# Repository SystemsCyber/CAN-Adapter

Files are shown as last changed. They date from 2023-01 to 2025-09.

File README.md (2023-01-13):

# CAN Adapter

The CANTool utilizes a Teensy 4.1 and a general expansion port as an add on if needed. There are three CAN channels available for use as well as 4 LED's to be programmed for desired use.

## Testing

There are a few test programs located in the tests folder allowing for the device's functions to be verified. The tests within the folder include tests for the SD card, all 3 CAN channels, LED blinking, and the D-SUB.

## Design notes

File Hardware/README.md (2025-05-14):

# Teeny 4 CAN Tool

This directory has PCB schematics, BOMs, and Altium PCB project files.

All components are through hole, so it is easy to build with just a soldering iron.

PDFs of the !(schematics)[Teensy%204%20CAN%20Tool%20Rev2%20Schematics.pdf] are available.

## Self-Assembly Instructions

If using a powered connection, pins 3 and 6 are shorted together on the ground pin. However, pin 6 can also be pin 9 of the dsub is inverted, which will short the power to ground. Therefore, please cut the trace between pin 3 and 6 on the bottom of Version 2 of the board on the DSUB connection.

### Materials

- Soldering iron
- Solder
- Teensy 4 CAN Tool PCB
- 30 AWG wire
- Wire cutters and strippers
- Good ventilation and lighting
- Bill of materials and all items listed
- PCB mount (recommended)
- Solder wick (recommended)

### Assembly

It is **highly** recommended assembling the board starting with the lowest profile components first (i.e. resistors and small capacitors) and the highest profile components near the end (i.e. headers, phoenix contacts, and jumpers). That way, it is much easier to align pins and solder the components properly or correct mistakes.

Solder items carefully, ensuring that pins are not bridged or lacking solder. Be wary of polarity for large capacitors and diodes. Properly dispose of component clippings.

The recommended order of population:

- Resistors (470 Ohm x4, 120 Ohm x3)
- Small Capacitors (0.1uF x3)
- IC (MCP2562 x3)
- LED's (GRN, YLW, RED, BLU)
- Headers (Female, 24 pin x2, 8 pin x2)
- Connectors (6 pin x1)
  - Cut into 3 sets of 2 pins each for the jumper connections
- Phoenix Contacts (x3)
- DSUB Connector
- Add terminating connections last (x3)

As for the Teensy 4.1 Board, solder (2x 24 pin Male Headers) then it can be directly placed onto the female headers on the CAN Tool PCB.

## Errata

The PCB board on revision 1 needs 30 AWG wire to be soldered from:

* CANH on Phoenix Connector to Pin 7 (CANH) on MCP2562 Designator U2
* Can RX/TX 3 to MCP2562 Designator U3
  * RX = Pin 30 On Teensy 4.1 -> Pin 4 (RX) on U3 MCP2562FD
  * TX = Pin 31 on Teensy 4.1 -> Pin 1 (TX) on U3 MCP2562FD

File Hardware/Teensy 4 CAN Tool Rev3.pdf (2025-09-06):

MikroBus Expansion | Vehicle Network Connection

# CAN Transceivers

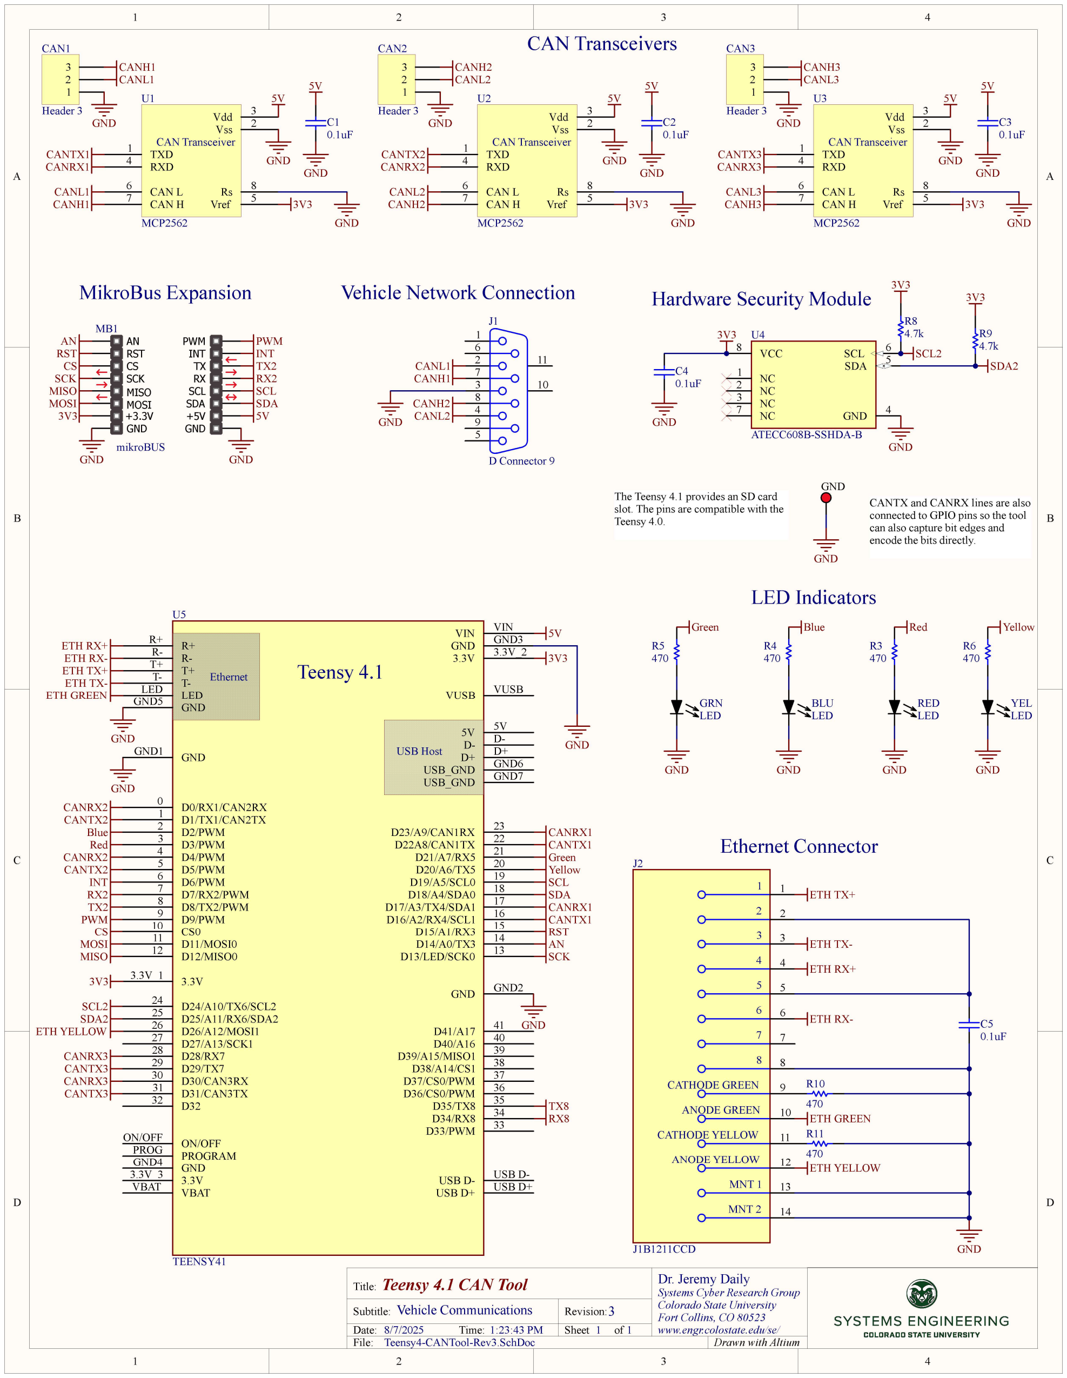
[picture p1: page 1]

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
Systems Cyber Research Group Colorado State University
Fort Collins, CO 80523

### 1 www.engr.colostate.edu/se/

## Teensy 4.1 CAN Tool

Vehicle Communications | 3
8/7/2025 | 1:23:43 PM
Teensy4-CANTool-Rev3.SchDoc

Title:

Subtitle:
Date:
File:

Revision:
Time: | Sheet | of
Drawn with Altium

### Dr. Jeremy Daily

3V3

GND
CANRX2
CANTX2

5V

CANRX1
CANTX1

TXD 1

Vss | 2
Vdd | 3

RXD 4

Vref 5

CAN L 6
CAN H 7

Rs 8

CAN Transceiver

U1

MCP2562

3V3

5V

GND

CANL1
CANH1
GND

1

2

3

CAN1

Header 3
GND

CANL1

CANRX1

CANTX1 | TXD 1
Vss | 2
Vdd | 3

RXD 4

Vref 5

CAN L 6
CAN H 7

Rs 8

CAN Transceiver

U2

MCP2562

3V3

5V

GND

CANL2
CANH2
GND

1

2

3

CAN2

Header 3
GND

CANL2

CANH2

CANRX2

CANTX2

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
Blue

GND | GND | GND GND
Green | Yellow Red

Green

Blue

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
D Connector 9

CANL1
CANH1

CANL2

CANH2
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
Yellow

CANRX3
CANTX3

TXD 1

Vss | 2
Vdd | 3

RXD 4

Vref 5

CAN L 6
CAN H 7

Rs 8

CAN Transceiver

U3

MCP2562

3V3

5V

GND

CANL3
CANH3
GND

1

2

3

CAN3

Header 3

CANL3

CANTX3
CANRX3

AN
RST
CS
SCK

MOSI

MISO

+3.3V
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
mikroBUS
GND | GND
3V3 | 5V

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
MOSI

MOSI

MISO

MISO

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
0.1uF

GND

5V

C2
0.1uF

GND

5V

C1
0.1uF

GND

5V

The Teensy 4.1 provides an SD card slot. The pins are compatible with the Teensy 4.0.

CANRX2
CANTX2

CANRX3
CANTX3

CANTX and CANRX lines are also connected to GPIO pins so the tool can also capture bit edges and encode the bits directly.

CANRX1
CANTX1

SCL2
SDA2

RX8

TX8

VCC 8

| SCL | 6
| SDA | 5
NC 1
NC 2
NC 3
NC 7 | GND | 4

U4

ATECC608B-SSHDA-B

C4
0.1uF

GND

GND

3V3

3V3
3V3

SCL2
SDA2

R8
4.7k | R9
| 4.7k

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
CATHODE GREEN

ANODE GREEN

CATHODE YELLOW

ANODE YELLOW

MNT 1

MNT 2

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
J1B1211CCD

# Ethernet Connector

VIN VIN

D5/PWM 5

PROGRAM PROG ON/OFF ON/OFF

D0/RX1/CAN2RX 0
D1/TX1/CAN2TX 1

D7/RX2/PWM 7
D8/TX2/PWM 8

D28/RX7 28
D29/TX7 29
D34/RX8 | 34 D35/TX8 | 35

D30/CAN3RX 30
D31/CAN3TX 31

D3/PWM 3
D4/PWM 4
D33/PWM | 33
D13/LED/SCK0 | 13 D14/A0/TX3 | 14 D15/A1/RX3 | 15 D16/A2/RX4/SCL1 | 16 D17/A3/TX4/SDA1 | 17 D18/A4/SDA0 | 18 D19/A5/SCL0 | 19 D20/A6/TX5 | 20 D21/A7/RX5 | 21 D22A8/CAN1TX | 22
5V | 5V

3.3V 3.3V_1

3.3V 3.3V_2

3.3V 3.3V_3

VUSB VUSB

VBAT VBAT

LED LED | T- T- | T+ T+ | R- R- | R+ R+
D+ | D+ D- | D-

D2/PWM 2

D6/PWM 6

D9/PWM 9

D32 32

D37/CS0/PWM | 37
D36/CS0/PWM | 36

CS0 10
D12/MISO0 12 | D11/MOSI0 11
D41/A17 | 41
D40/A16 | 40
D39/A15/MISO1 | 39
D38/A14/CS1 | 38
D27/A13/SCK1 27 | D26/A12/MOSI1 26 | D25/A11/RX6/SDA2 25 | D24/A10/TX6/SCL2 24
D23/A9/CAN1RX | 23

GND GND1

GND | GND2
GND | GND3

GND GND4

GND GND5

USB_GND | GND6
USB_GND | GND7
Ethernet | Teensy 4.1

USB Host

USB D+ | USB D+ USB D- | USB D-

U5

TEENSY41

GND

GND

3V3

GND

C5
0.1uF

R10
470

R11
470

GND

ETH TX+

ETH TX+

ETH TX-

ETH TX-

ETH RX+

ETH RX+

ETH RX-

ETH RX-

ETH GREEN

ETH GREEN

ETH YELLOW

CANH1

GND

CANH3

ETH YELLOW

GND

GND

# Hardware Security Module

# LED Indicators

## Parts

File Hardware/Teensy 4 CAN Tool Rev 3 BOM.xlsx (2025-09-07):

Comment | Description | Designator | Quantity | Manufacturer 1 | Manufacturer Part Number 1 | Supplier 1 | Supplier Part Number 1 | Alternative
470 | 470 Ohms ±5% 0.25W, 1/4W Through Hole Resistor Axial Automotive AEC-Q200 Carbon Film | R3 | 1 | YAGEO | CFR-25JB-52-470R | Digi-Key | 470QBK-ND | Allowed
470 | 470 Ohms ±5% 0.25W, 1/4W Through Hole Resistor Axial Automotive AEC-Q200 Carbon Film | R4 | 1 | YAGEO | CFR-25JB-52-470R | Digi-Key | 470QBK-ND | Allowed
470 | 470 Ohms ±5% 0.25W, 1/4W Through Hole Resistor Axial Automotive AEC-Q200 Carbon Film | R5 | 1 | YAGEO | CFR-25JB-52-470R | Digi-Key | 470QBK-ND | Allowed
470 | 470 Ohms ±5% 0.25W, 1/4W Through Hole Resistor Axial Automotive AEC-Q200 Carbon Film | R6 | 1 | YAGEO | CFR-25JB-52-470R | Digi-Key | 470QBK-ND | Allowed
470 | 470 Ohms ±5% 0.25W, 1/4W Through Hole Resistor Axial Automotive AEC-Q200 Carbon Film | R10 | 1 | YAGEO | CFR-25JB-52-470R | Digi-Key | 470QBK-ND | Allowed
470 | 470 Ohms ±5% 0.25W, 1/4W Through Hole Resistor Axial Automotive AEC-Q200 Carbon Film | R11 | 1 | YAGEO | CFR-25JB-52-470R | Digi-Key | 470QBK-ND | Allowed
0.1uF | 0.1 µF ±10% 50V Ceramic Capacitor X7R Radial | C1 | 1 | Vishay | K104K15X7RF53H5 | Digi-Key | BC3323-ND | Allowed
0.1uF | 0.1 µF ±10% 50V Ceramic Capacitor X7R Radial | C2 | 1 | Vishay | K104K15X7RF53H5 | Digi-Key | BC3323-ND | Allowed
0.1uF | 0.1 µF ±10% 50V Ceramic Capacitor X7R Radial | C3 | 1 | Vishay | K104K15X7RF53H5 | Digi-Key | BC3323-ND | Allowed
0.1uF | 0.1 µF ±10% 50V Ceramic Capacitor X7R Radial | C4 | 1 | Vishay | K104K15X7RF53H5 | Digi-Key | BC3323-ND | Allowed
0.1uF | 0.1 µF ±10% 50V Ceramic Capacitor X7R Radial | C5 | 1 | Vishay | K104K15X7RF53H5 | Digi-Key | BC3323-ND | Allowed
4.7k | 4.7 kOhms ±5% 0.25W, 1/4W Through Hole Resistor Axial Automotive AEC-Q200 Carbon Film | R8 | 1 | YAGEO | CFR-25JB-52-4K7 | Digi-Key | 13-CFR-25JB-52-4K7-ND | Allowed
4.7k | 4.7 kOhms ±5% 0.25W, 1/4W Through Hole Resistor Axial Automotive AEC-Q200 Carbon Film | R9 | 1 | YAGEO | CFR-25JB-52-4K7 | Digi-Key | 13-CFR-25JB-52-4K7-ND | Allowed
ATECC608B | Authentication Chip 8-SOIC | U4 | 1 | Microchip | ATECC608B-SSHDA-B | Digi-Key | 150-ATECC608B-SSHDA-B-ND | None
D Connector 9 | 9 Position D-Sub Plug, Male Pins Connector | J1 | 1 | Assmann | A-DS 09 A/KG-T2S | Digi-Key | AE10968-ND | Allowed
Header 3 | 3 Position Wire to Board Terminal Block Horizontal with Board 0.197" (5.00mm) Through Hole | CAN1 | 1 | Phoenix Contact | 1935174 | Digikey | 277-1578-ND | Allowed
Header 3 | 3 Position Wire to Board Terminal Block Horizontal with Board 0.197" (5.00mm) Through Hole | CAN2 | 1 | Phoenix Contact | 1935174 | Digikey | 277-1578-ND | Allowed
Header 3 | 3 Position Wire to Board Terminal Block Horizontal with Board 0.197" (5.00mm) Through Hole | CAN3 | 1 | Phoenix Contact | 1935174 | Digikey | 277-1578-ND | Allowed
J1B1211CCD | CONN JACK 1PORT 100 BASE-T PCB | J2 | 1 | Würth Elektronik | 7499011121A | Digi-Key | 732-4509-5-ND | Allowed
LED | Blue 470nm LED Indication - Discrete 3.2V Radial | BLU | 1 | Würth Elektronik | 151051BS04000 | Digi-Key | 732-5015-ND | Allowed
LED | Green 572nm LED Indication - Discrete 2.1V Radial | GRN | 1 | Würth Elektronik | 151051VS04000 | Digi-Key | 732-5017-ND | Allowed
LED | Red 645nm LED Indication - Discrete 2.1V Radial | RED | 1 | Würth Elektronik | 151051RS11000 | Digi-Key | 732-5016-ND | Allowed
LED | Yellow 590nm LED Indication - Discrete 2V Radial | YEL | 1 | Würth Elektronik | 151051YS04000 | Digi-Key | 732-5018-ND | Allowed
MCP2562 | 1/1 Transceiver CANbus 8-PDIP | U1 | 1 | Microchip | MCP2562FD-E/P | Digi-Key | MCP2562FD-E/P-ND | None
MCP2562 | 1/1 Transceiver CANbus 8-PDIP | U2 | 1 | Microchip | MCP2562FD-E/P | Digi-Key | MCP2562FD-E/P-ND | None
MCP2562 | 1/1 Transceiver CANbus 8-PDIP | U3 | 1 | Microchip | MCP2562FD-E/P | Digi-Key | MCP2562FD-E/P-ND | None
TEENSY41 | PJRC Teensy 4.1 Development Board | U5 | 1 | SparkFun | 16996 | Digi-Key | 1568-16996-ND | None
TEENSY41Headers | TEENSY STACKABLE HEADER KIT (EXT | U5a | 1 | SparkFun | 17152 | Digi-Key | 1568-17152-ND | Allowed
ETHHeader-M | Connector Header Through Hole 6 position 0.079" (2.00mm) | U5b | 1 | GCT | BF050-06-A-B-0400-0300-L-G | Digi-Key | 2073-BF050-06-A-B-0400-0300-L-G-ND | Allowed
ETHHeader-F | 6 Position Receptacle Connector 0.079" (2.00mm) Through Hole Gold | U5c | 1 | TE/AMP | 2314820-6 | Digi-Key | 17-2314820-6-ND | Allowed

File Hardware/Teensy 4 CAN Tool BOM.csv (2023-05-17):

Line # | Name | Description | Designator | Quantity | Manufacturer 1 | Manufacturer Part Number 1 | Manufacturer Lifecycle 1 | Supplier 1 | Supplier Part Number 1 | Supplier Unit Price 1 | Supplier Subtotal 1
1 | Board Headers | 24 pin sockets |  | 2 | Sullins | PPPC241LFBN-RC | Volume Production | Digi-Key | S7057-ND | 1.43 | 2.86
2 | Teensy Headers | 24 pins spaced 0.100" apart |  | 2 | Sullins | PRPC024SFAN-RC | Volume Production | Digi-Key | S1211EC-24-ND | 0.68 | 1.36
3 | Term Resistor Header | 6 Pins to hold shunts |  | 1 | Sullins | PRPC006SFAN-RC | Volume Production | Digi-Key | S1211EC-06-ND | 0.21 | 0.21
4 | LED | Blue 470nm LED Indication - Discrete 3.2V Radial | BLU | 1 | Wurth Electronics | 151051BS04000 | Volume Production | Digi-Key | 732-5015-ND | 0.26 | 0.26
 | 0.1uF | 0.1µF ±10% 50V Ceramic Capacitor X7R 0603 (1608 Metric) | C1, C2, C3 | 3 | Vishay BCcomponents | K104K15X7RF53H5 | Unknown | Digi-Key | BC3323-ND | 0.23 | 0.69
5 | Header 3 | Header, 3-Pin | CAN1, CAN2, CAN3 | 3 | Phoenix Contact | PT1.5/3-5.0-H | Volume Production | Digi-Key | 277-1578-ND | 0.71 | 2.13
6 | LED | Green 572nm LED Indication - Discrete 2.1V Radial | GRN | 1 | Wurth Electronics | 151051VS04000 | Volume Production | Digi-Key | 732-5017-ND | 0.26 | 0.26
7 | D Connector 9 | CONN D-SUB PLUG 9POS R/A SLDR | J1 | 1 | Assmann | A-DS-09-A/KG-T2S | Volume Production | Digi-Key | AE10968-ND | 0.78 | 0.78
 | Header 2 | Header, 2-Pin | P1 | 1
8 | 120 | 120 Ohms ±5% 0.25W, 1/4W Through Hole Resistor Axial Carbon Film | R1, R2, R7 | 3 | Yageo | CFR-25JB-52-120R | Volume Production | Digi-Key | 120QBK-ND | 0.1 | 0.3
9 | 470 | 470 Ohms ±5% 0.25W, 1/4W Through Hole Resistor Axial Carbon Film | R3, R4, R5, R6 | 4 | Yageo | CFR-25JB-52-470R | Volume Production | Digi-Key | 470QBK-ND | 0.1 | 0.4
10 | LED | Red 645nm LED Indication - Discrete 2.1V Radial | RED | 1 | Wurth Electronics | 151051RS11000 | Volume Production | Digi-Key | 732-5016-ND | 0.17 | 0.17
11 | Teensy 4.1 | 32 Bit Arduino-Compatible iMX Microcontroller | Teensy 4.1 | 1 | SparkFun | 16771 | Unknown | Digi-Key | 1568-DEV-16771-ND | 33.08 | 33.08
12 | Header 2 | 2 (1 x 2) Position Shunt Connector Open Top, Grip 0.100" (2.54mm) Gold | Term1, Term2, Term3 | 3 | Sullins | NPC02SXON-RC | Volume Production | Digi-Key | S9341-ND | 0.11 | 0.33
13 | MCP2562 | 1/1 Transceiver CANbus 8-PDIP | U1, U2, U3 | 3 | Microchip | MCP2562FD-E/P | Volume Production | Digi-Key | MCP2562FD-E/P-ND | 1.38 | 4.14
14 | LED | Yellow 590nm LED Indication - Discrete 2V Radial | YEL | 1 | Wurth Electronics | 151051YS04000 | Volume Production | Digi-Key | 732-5018-ND | 0.23 | 0.23

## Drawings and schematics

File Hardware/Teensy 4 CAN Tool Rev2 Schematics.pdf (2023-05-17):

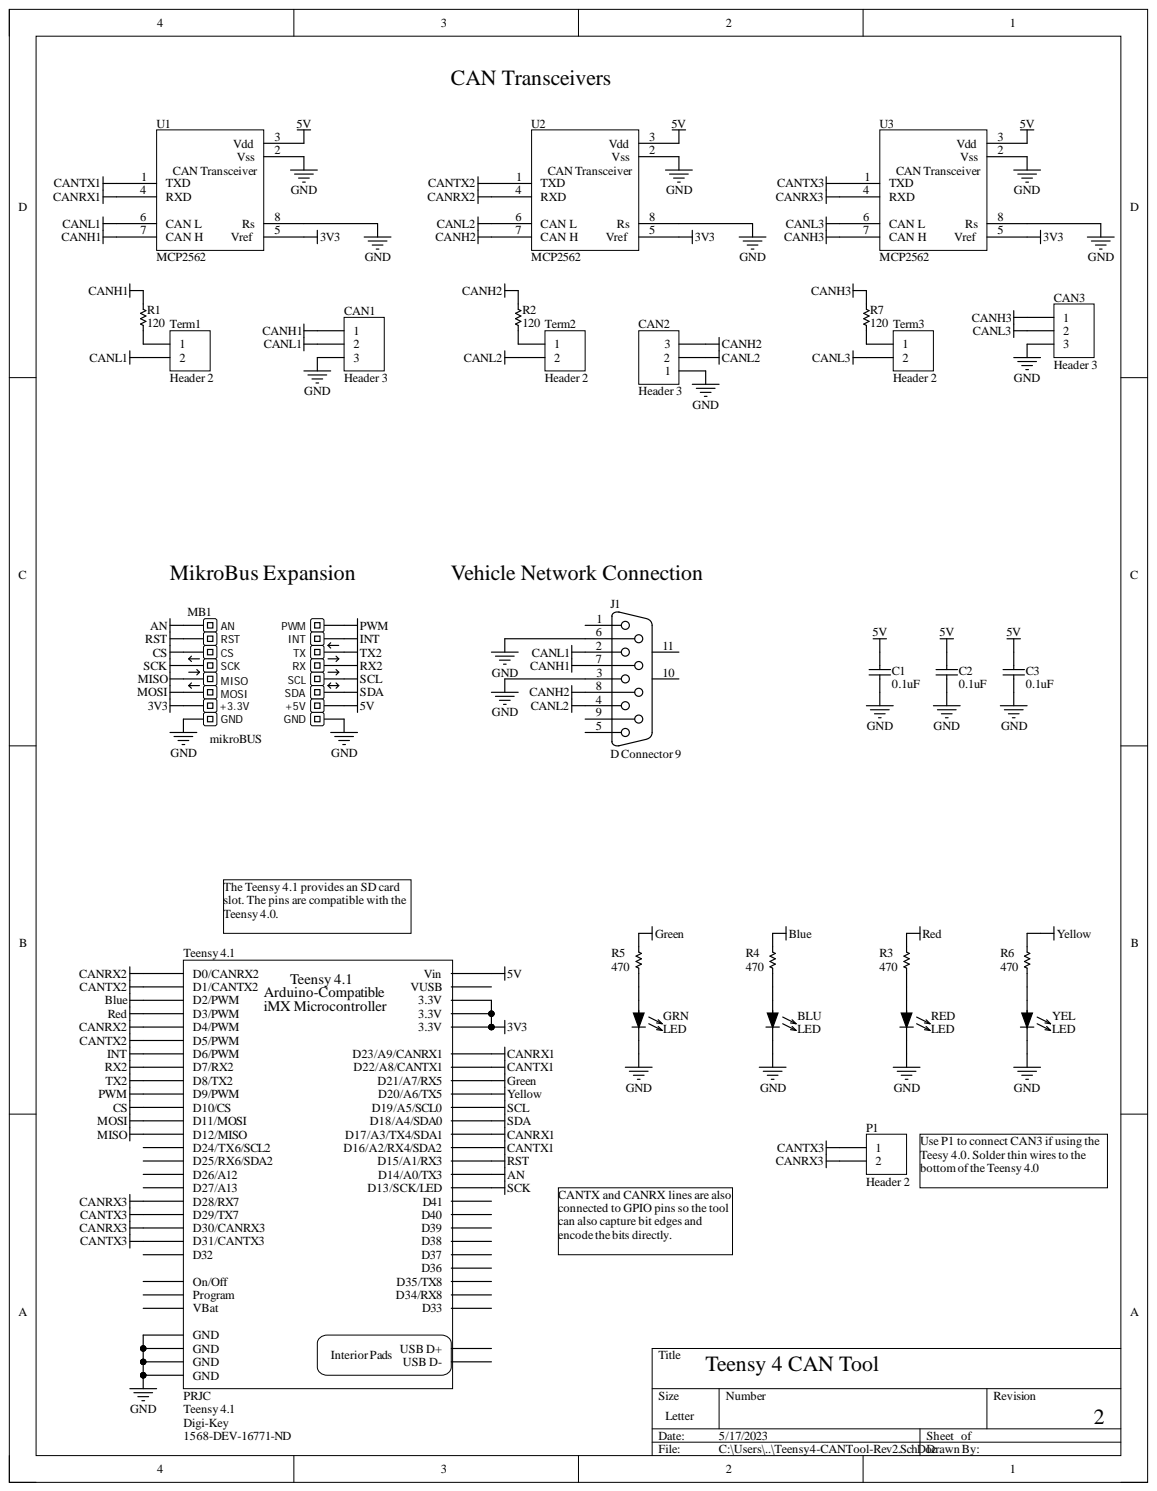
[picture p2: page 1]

B | GND | B

The Teensy 4.1 provides an SD card
slot. The pins are compatible with the
Teensy 4.0.

Use P1 to connect CAN3 if using the
Teesy 4.0. Solder thin wires to the
bottomof theTeensy 4.0

CANTX and CANRX lines are also
connected to GPIO pins so the tool
can also capture bit edges and
encode the bits directly.

Date: 5/17/2023 | Sheet of
File: C:\Users\..\Teensy4-CANTool-Rev2.SchDoDra c wnBy:

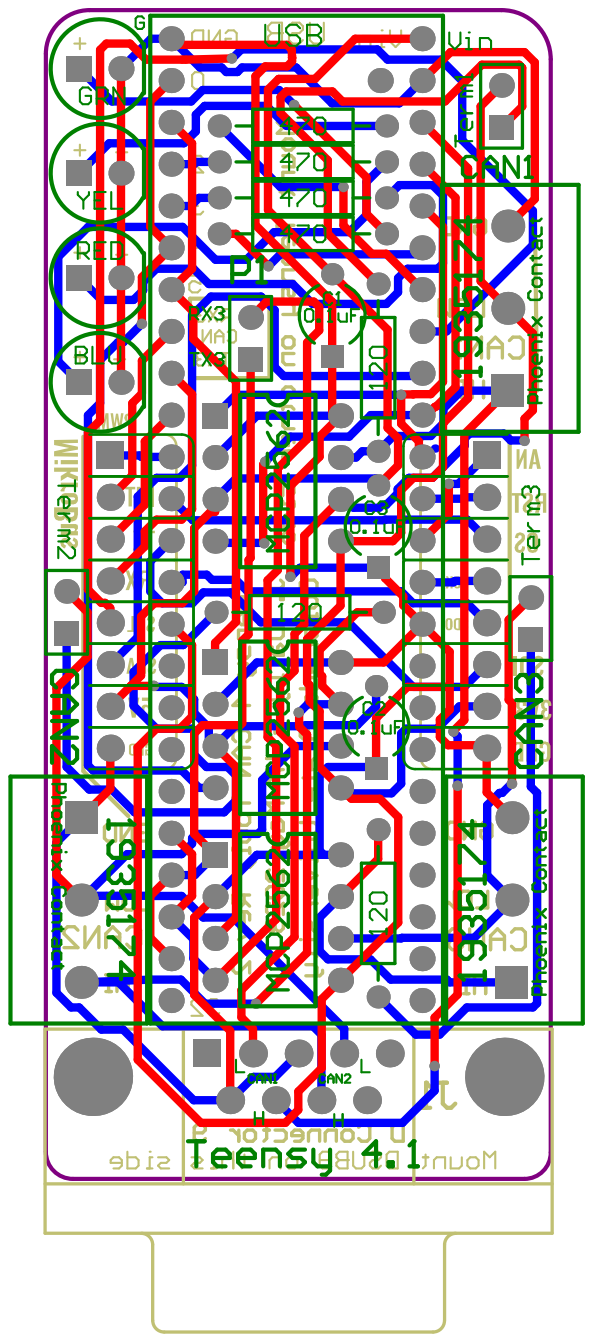
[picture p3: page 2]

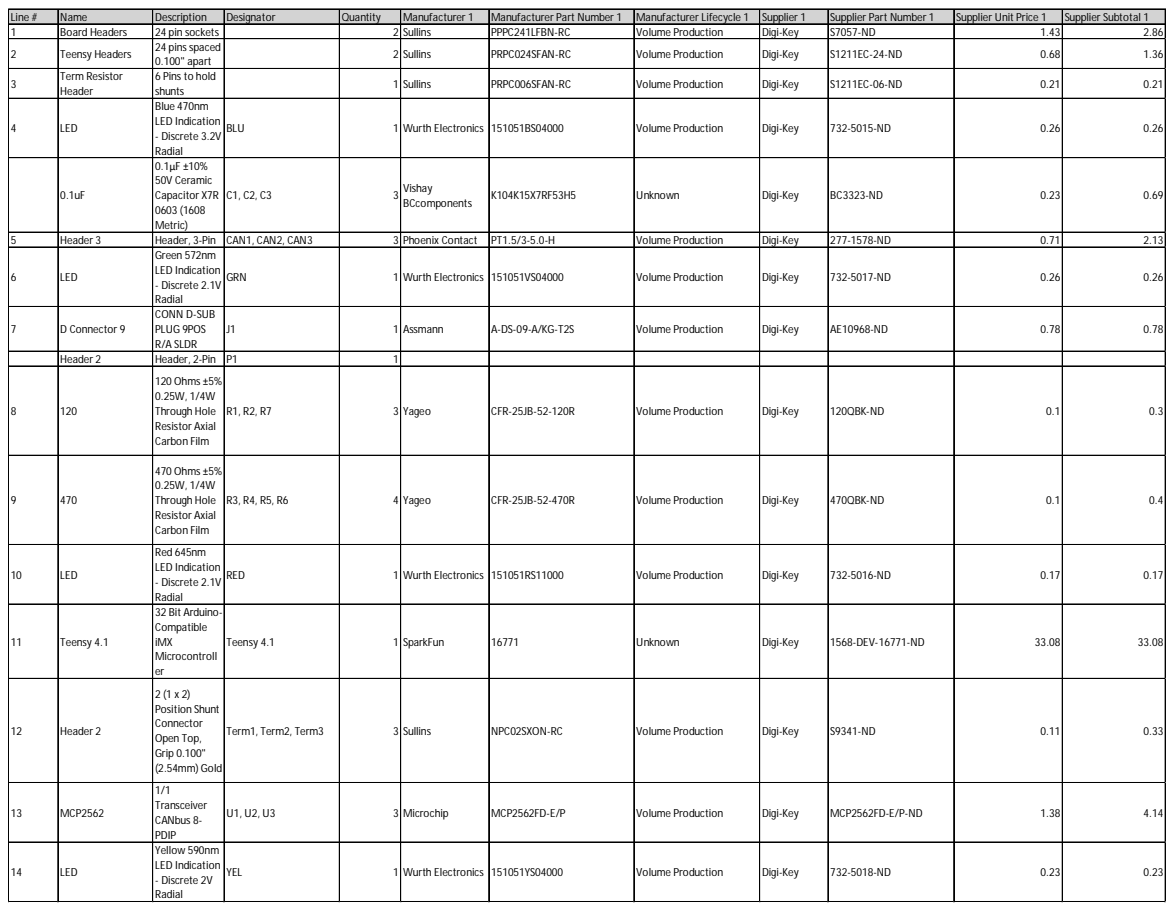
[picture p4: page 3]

Line # | Name | Description | Designator | Quantity | Manufacturer 1 | Manufacturer Part Number 1 | Manufacturer Lifecycle 1 | Supplier 1 | Supplier Part Number 1 | Supplier Unit Price 1 | Supplier Subtotal 1
1 | Board Headers | 24 pin sockets | | 2 | Sullins | PPPC241LFBN-RC | Volume Production | Digi-Key | S7057-ND | 1.43 | 2.86
2 | Teensy Headers | 24 pins spaced 0.100" apart | | 2 | Sullins | PRPC024SFAN-RC | Volume Production | Digi-Key | S1211EC-24-ND | 0.68 | 1.36

3 | Term Resistor Header | 6 Pins to hold shunts | | 1 | Sullins | PRPC006SFAN-RC | Volume Production | Digi-Key | S1211EC-06-ND | 0.21 | 0.21

4 | LED | Blue 470nm LED Indication - Discrete 3.2V Radial | BLU | 1 | Wurth Electronics | 151051BS04000 | Volume Production | Digi-Key | 732-5015-ND | 0.26 | 0.26

0.1uF | 0.1µF ±10% 50V Ceramic Capacitor X7R 0603 (1608 Metric) | C1, C2, C3 | 3 | Vishay BCcomponents | K104K15X7RF53H5 | Unknown | Digi-Key | BC3323-ND | 0.23 | 0.69

5 | Header 3 | Header, 3-Pin | CAN1, CAN2, CAN3 | 3 | Phoenix Contact | PT1.5/3-5.0-H | Volume Production | Digi-Key | 277-1578-ND | 0.71 | 2.13
6 | LED | Green 572nm LED Indication - Discrete 2.1V Radial | GRN | 1 | Wurth Electronics | 151051VS04000 | Volume Production | Digi-Key | 732-5017-ND | 0.26 | 0.26

7 | D Connector 9 | CONN D-SUB PLUG 9POS R/A SLDR | J1 | 1 | Assmann | A-DS-09-A/KG-T2S | Volume Production | Digi-Key | AE10968-ND | 0.78 | 0.78

Header 2 | Header, 2-Pin | P1 | 1

8 | 120 | 120 Ohms ±5% 0.25W, 1/4W Through Hole Resistor Axial Carbon Film | R1, R2, R7 | 3 | Yageo | CFR-25JB-52-120R | Volume Production | Digi-Key | 120QBK-ND | 0.1 | 0.3

9 | 470 | 470 Ohms ±5% 0.25W, 1/4W Through Hole Resistor Axial Carbon Film | R3, R4, R5, R6 | 4 Yageo | | CFR-25JB-52-470R | Volume Production | Digi-Key | 470QBK-ND | 0.1 | 0.4

10 | LED | Red 645nm LED Indication - Discrete 2.1V Radial | RED | 1 | Wurth Electronics | 151051RS11000 | Volume Production | Digi-Key | 732-5016-ND | 0.17 | 0.17

11 | Teensy 4.1 | 32 Bit Arduino-Compatible iMX Microcontroll er | Teensy 4.1 | 1 | SparkFun | 16771 | Unknown | Digi-Key | 1568-DEV-16771-ND | 33.08 | 33.08

12 | Header 2 | 2 (1 x 2) Position Shunt Connector Open Top, Grip 0.100" (2.54mm) Gold | Term1, Term2, Term3 | 3 | Sullins | NPC02SXON-RC | Volume Production | Digi-Key | S9341-ND | 0.11 | 0.33

13 | MCP2562 | 1/1 Transceiver CANbus 8-PDIP | U1, U2, U3 | 3 | Microchip | MCP2562FD-E/P | Volume Production | Digi-Key | MCP2562FD-E/P-ND | 1.38 | 4.14

14 | LED | Yellow 590nm LED Indication - Discrete 2V Radial | YEL | 1 | Wurth Electronics | 151051YS04000 | Volume Production | Digi-Key | 732-5018-ND | 0.23 | 0.23

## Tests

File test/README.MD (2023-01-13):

# Testing Information

This directory is intended for PlatformIO Unit testing using Unity.

This directory contains tests for the CAN adapater in order to prove full functionality of the device once assembled. These tests include:

* CAN communication:

  * Tests that the device is able to send and recieve CAN messages on CAN1, CAN2, and CAN3
* LED:

  * This turns the LEDS on and off that is for the user to visually confirm
* Logging Capabilities:

  * Tests that the Teensy 4.1 is able to write and read to the SD card
  * Will also test SD logging speed with full bus load

More information about PIO Unit Testing:

* https://github.com/platformio/platform-teensy/tree/master

- https://docs.platformio.org/page/plus/unit-testing.html
- https://docs.platformio.org/en/latest/core/userguide/cmd_test.html#cmd-test

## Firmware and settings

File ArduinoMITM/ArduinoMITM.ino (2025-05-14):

#include <FlexCAN_T4.h>
/* load the libaries needed to use 2 CAN channels on the Teensy 4*/
FlexCAN_T4<CAN1, RX_SIZE_256, TX_SIZE_16> Can1;
FlexCAN_T4<CAN2, RX_SIZE_256, TX_SIZE_16> Can2;

/* Setup the pin numbers that corresond to the different LEDs*/
#define GREEN_LED 21
#define RED_LED 3
#define YELLOW_LED 20
#define BLUE_LED 2

/* Define a timeout in milliseconds to turn off the LEDs if the have been turned on*/
#define LED_TIMEOUT 200

/* Declare the state of the LEDs*/
boolean GREEN_LED_state;
boolean RED_LED_state;
boolean YELLOW_LED_state;
boolean BLUE_LED_state;

/* Setup the timers for tracking how long the LEDs are on. This is a utility funtion 
supplied with the Teensyduino Addon to Arduino*/
elapsedMillis green_toggle_timer;
elapsedMillis red_toggle_timer;
elapsedMillis yellow_toggle_timer;
elapsedMillis blue_toggle_timer;

elapsedMillis light_send;

#define TRIGGER_PIN 10
bool trigger_state;

void send_light_command();

void setup(void) {
  // set mode for trigger pin
  pinMode(TRIGGER_PIN,INPUT);


  //Keep the Builtin LED (pin 13) on the whole time to show it's plugged in
  pinMode(LED_BUILTIN, OUTPUT);
  digitalWrite(LED_BUILTIN, HIGH);

  /*Start the CAN channels. Adjust the bit rate as needed */
  Can1.begin();
  Can1.setBaudRate(250000);
  Can1.setMaxMB(16);
  Can1.enableFIFO();
  Can1.enableFIFOInterrupt();
  Can1.onReceive(can1Sniff);
  Can1.mailboxStatus();

  Can2.begin();
  Can2.setBaudRate(250000);
  Can2.setMaxMB(16);
  Can2.enableFIFO();
  Can2.enableFIFOInterrupt();
  Can2.onReceive(can2Sniff);
  Can2.mailboxStatus();

  /* Startup the LEDs*/
  pinMode(GREEN_LED,OUTPUT);
  pinMode(RED_LED,OUTPUT);
  pinMode(YELLOW_LED,OUTPUT);
  pinMode(BLUE_LED,OUTPUT);
  GREEN_LED_state = HIGH;
  YELLOW_LED_state = HIGH;
  RED_LED_state = HIGH;
  BLUE_LED_state = HIGH;
  
  check_led_timers();
}

/*
Show the CAN messages as they come in over Serial. This function "
is not necessary and is supplied for debugging.
*/
void print_CAN(const CAN_message_t &msg){

 // Serial.print("MB "); Serial.print(msg.mb);
 // Serial.print("  OVERRUN: "); Serial.print(msg.flags.overrun);
 // Serial.print("  LEN: "); Serial.print(msg.len);
 // Serial.print(" EXT: "); Serial.print(msg.flags.extended);
 // Serial.print(" TS: "); Serial.print(msg.timestamp);
 // Serial.print(" ID: "); 
  Serial.print(msg.id, HEX);
  Serial.print(" ");
  for ( uint8_t i = 0; i < msg.len; i++ ) {
    Serial.printf("%02X ",msg.buf[i]);
  } Serial.println();
}

void can1Sniff(const CAN_message_t &msg) {
  YELLOW_LED_state = !YELLOW_LED_state;
  yellow_toggle_timer = 0;
  print_CAN(msg); 

  //Make a new message based on the old one.
  CAN_message_t new_msg = msg;
  
  // Determine the J1939 Parameter Group Number
  // only handle PDU 2 formatted messages now
  unsigned long pgn = (msg.id & 0x00FFFF00) >> 8;
  
  // Change the message values for each byte as you wish
  //0CEFC180#5A64FF00FFFFFFFF
  // if (pgn == 0xEFC1){ //0xFEF1
  //   new_msg.buf[0]=byte(.2*msg.buf[0]);
  //   // new_msg.buf[1]=0x11;
  //   // new_msg.buf[2]=0x22;
  //   // new_msg.buf[3]=0x33;
  //   // new_msg.buf[4]=0x44;
  //   // new_msg.buf[5]=0x55;
  //   // new_msg.buf[6]=0x66;
  //   // new_msg.buf[7]=0x77;
  //   new_msg.id=0x0CEFC780;
  // }
  // else if (pgn == 0xEFC7){ // Look for another PGN
  //   new_msg.id=0x0CEFC180;
  // }
  // else {
  //   //Do nothing. the new message is the same as the old one.
  // }
  
  // Write the new message on the other channel.
  Can2.write(new_msg);
  GREEN_LED_state = !GREEN_LED_state;
  green_toggle_timer = 0;
}

/*
This routine is sends messages the other direction.
*/
void can2Sniff(const CAN_message_t &msg) {
  BLUE_LED_state = !BLUE_LED_state;
  blue_toggle_timer = 0;
  //print_CAN(msg);

  CAN_message_t new_msg = msg;
  //Add code to look for Ids and manipulate them here.
  Can1.write(new_msg);
  RED_LED_state = !RED_LED_state;
  red_toggle_timer = 0;
}

void check_led_timers(){
  if (red_toggle_timer > LED_TIMEOUT){RED_LED_state = LOW;}
  if (blue_toggle_timer > LED_TIMEOUT){BLUE_LED_state = LOW;}
  if (green_toggle_timer > LED_TIMEOUT){GREEN_LED_state = LOW;}
  if (yellow_toggle_timer > LED_TIMEOUT){YELLOW_LED_state = LOW;}
  digitalWrite(GREEN_LED,GREEN_LED_state);
  digitalWrite(RED_LED,RED_LED_state);
  digitalWrite(YELLOW_LED,YELLOW_LED_state);
  digitalWrite(BLUE_LED,BLUE_LED_state);
}

void loop() {
  Can1.events(); // These calls write events to the network
  Can2.events();
  check_led_timers();

}

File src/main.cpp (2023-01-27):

/*
 * Blink
 * Turns on an LED on for one second,
 * then off for one second, repeatedly.
 */

#include <Arduino.h>
#include "unity.h"

void setup()
{
  // initialize LED digital pin as an output.
  pinMode(LED_BUILTIN, OUTPUT);
}

void loop()
{
  // turn the LED on (HIGH is the voltage level)
  digitalWrite(LED_BUILTIN, HIGH);
  // wait for a second
  delay(1000);
  // turn the LED off by making the voltage LOW
  digitalWrite(LED_BUILTIN, LOW);
   // wait for a second
  delay(1000);
}

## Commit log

2023-05-17 Rev 2
    [Teensy 4 CAN Tool BOM.csv, Teensy 4 CAN Tool BOM.xlsx, Teensy 4 CAN Tool.PrjPcb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]
2023-06-11 Added Comments and switched PGNs
2025-09-06 Added Rev3 Hardware
    [Teensy 4 CAN Tool BOM.csv, Teensy 4 CAN Tool BOM.xlsx, Teensy 4 CAN Tool.PrjPcb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]
2025-09-07 Create Teensy 4 CAN Tool Rev 3 BOM.xlsx
    [Teensy 4 CAN Tool Rev 3 BOM.xlsx]
